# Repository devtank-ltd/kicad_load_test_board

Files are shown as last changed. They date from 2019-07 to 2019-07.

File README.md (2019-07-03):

# kicad_load_test_board
A software controlled load test board for resistive load testing of products

Copyright Devtank Ltd 2019.

This documentation describes Open Hardware and is licensed under the CERN OHL v. 1.2.
You may redistribute and modify this documentation under the terms of the CERN OHL v.1.2. (http://ohwr.org/cernohl). This documentation is distributed WITHOUT ANY EXPRESS OR IMPLIED WARRANTY, INCLUDING OF MERCHANTABILITY, SATISFACTORY QUALITY AND FITNESS FOR A PARTICULAR PURPOSE. Please see the CERN OHL v.1.2 for applicable conditions

This folder contains the load test board hardware schematics and pcb layout files 

You will need Kicad to open hardware design files.

Test and measurement products can be purchased directly from Devtank Ltd.

Please contact:
Tim Telford
Technical Director - Devtank Ltd
+44 (0)1335 818014

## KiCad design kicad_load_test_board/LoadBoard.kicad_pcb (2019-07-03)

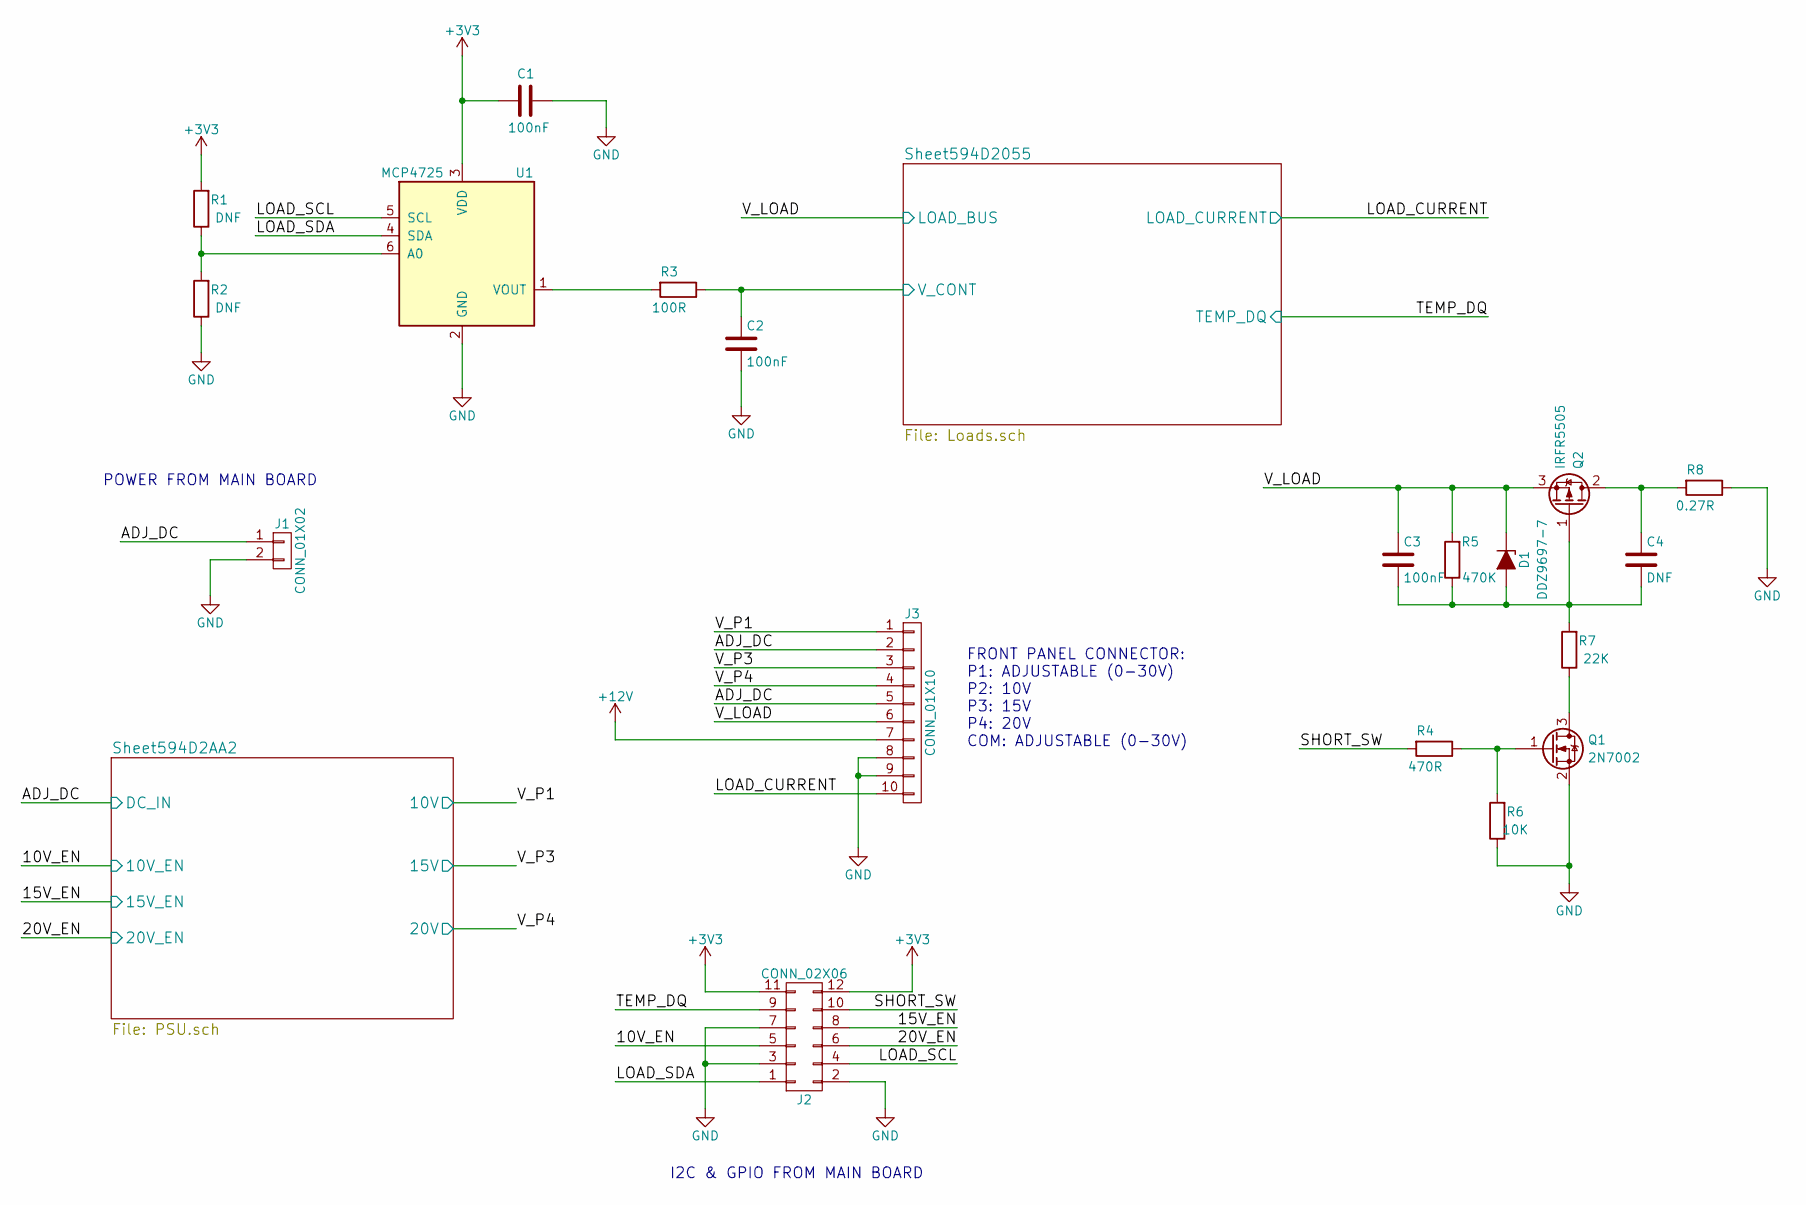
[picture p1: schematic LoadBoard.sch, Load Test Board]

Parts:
C1, C2, C3: 100nF; C_0603
C4: DNF; C_0603
D1: DDZ9697-7; D_SOD-123
J1: CONN_01X02; Molex_MiniFit-JR-5556-02A_2x01x4.20mm_Straight
J2: CONN_02X06; IDC_Header_Straight_12pins
J3: CONN_01X10; Molex_KK-6410-10_10x2.54mm_Straight
Q1: 2N7002; SOT-23
Q2: IRFR5505; TO-252-3_TabPin2
R1, R2: DNF; R_0603
R3: 100R; R_0603
R4: 470R; R_0603
R5: 470K; R_0603
R6: 10K; R_0603
R7: 22K; R_0603
R8: 0.27R; R_2816
U1: MCP4725; SOT-23-6

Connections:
+3V3: C1.2, J2.11, J2.12, R1.2, U1.3 (VDD); also elsewhere on the board
+12V: J3.7; also elsewhere on the board
/10V_EN: J2.5; also elsewhere on the board
/15V_EN: J2.8; also elsewhere on the board
/20V_EN: J2.6; also elsewhere on the board
/ADJ_DC: J1.1, J3.2, J3.5; also elsewhere on the board
/LOAD_CURRENT: J3.10; also elsewhere on the board
/LOAD_SCL: J2.4, U1.5 (SCL)
/LOAD_SDA: J2.1, U1.4 (SDA)
/SHORT_SW: J2.10, R4.2
/Sheet594D2055/V_CONT: C2.1, R3.1; also elsewhere on the board
/TEMP_DQ: J2.9; also elsewhere on the board
/V_LOAD: C3.1, D1.1 (K), J3.6, Q2.3 (S), R5.2; also elsewhere on the board
/V_P1: J3.1; also elsewhere on the board
/V_P3: J3.3; also elsewhere on the board
/V_P4: J3.4; also elsewhere on the board
GND: C1.1, C2.2, J1.2, J2.2, J2.3, J2.7, J3.8, J3.9, Q1.2 (S), R2.1, R6.1, R8.1, U1.2 (GND); also elsewhere on the board
unnamed: C3.2, C4.2, D1.2 (A), Q2.1 (G), R5.1, R7.2
unnamed: C4.1, Q2.2 (D), R8.2
unnamed: Q1.1 (G), R4.1, R6.2
unnamed: Q1.3 (D), R7.1
unnamed: R1.1, R2.2, U1.6 (A0)
unnamed: R3.2, U1.1 (VOUT)

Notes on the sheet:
POWER FROM MAIN BOARD
I2C & GPIO FROM MAIN BOARD
FRONT PANEL CONNECTOR: P1: ADJUSTABLE (0-30V) P2: 10V P3: 15V P4: 20V COM: ADJUSTABLE (0-30V)

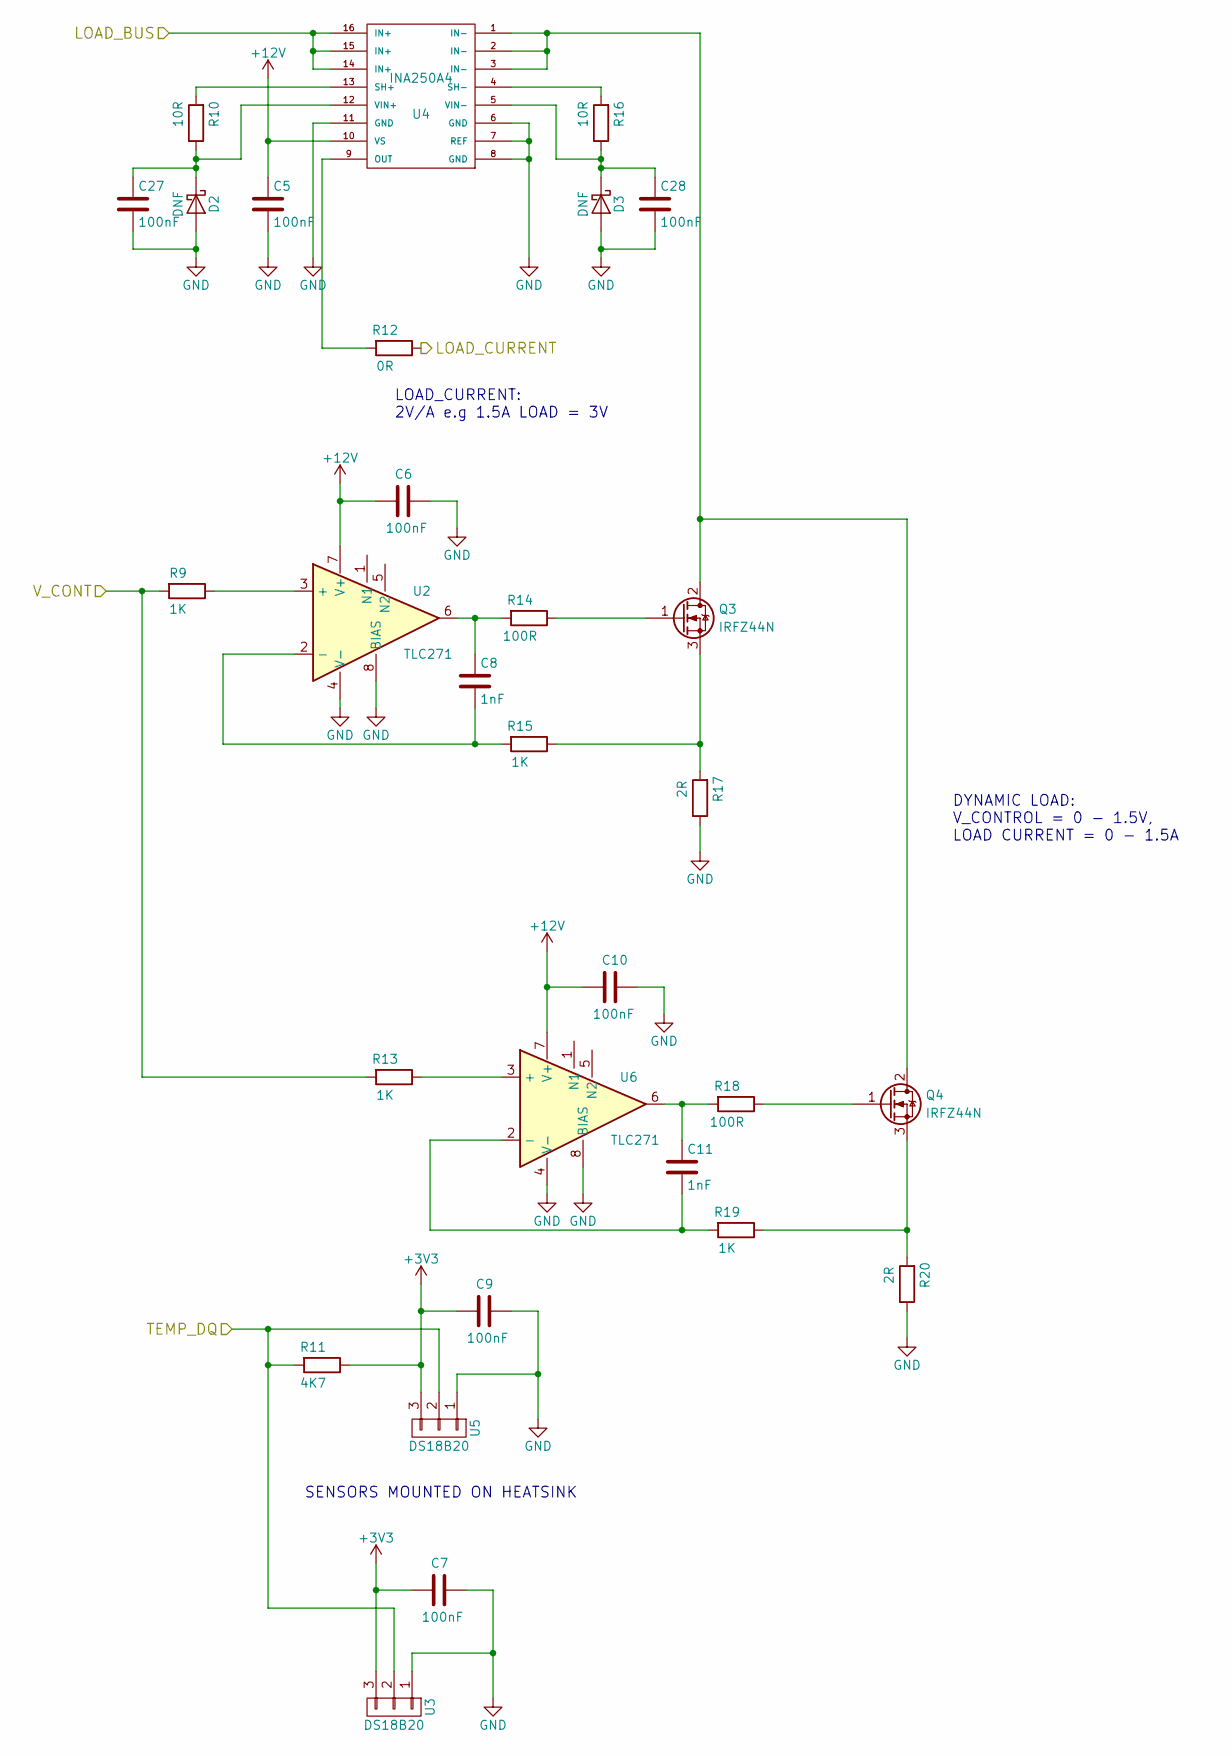
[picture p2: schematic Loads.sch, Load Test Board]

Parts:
C5, C6, C7, C9, C10, C27, C28: 100nF; C_0603
C8, C11: 1nF; C_0603
D2, D3: DNF; D_SOD-123
Q3, Q4: IRFZ44N; TO-220_Vertical
R9, R13, R15, R19: 1K; R_0603
R10, R16: 10R; R_0603
R11: 4K7; R_0603
R12: 0R; R_0603
R14, R18: 100R; R_0603
R17, R20: 2R; R_4527
U2, U6: TLC271; SOIC-8_3.9x4.9mm_Pitch1.27mm
U3, U5: DS18B20; TO-92_Inline_Narrow_Oval
U4: INA250A4; TSSOP-16_4.4x5mm_Pitch0.65mm

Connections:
+3V3: C7.2, C9.2, R11.1, U3.3, U5.3; also elsewhere on the board
+12V: C5.1, C6.2, C10.2, U2.7 (V+), U4.10 (VS), U6.7 (V+); also elsewhere on the board
/LOAD_CURRENT: R12.1; also elsewhere on the board
/Sheet594D2055/V_CONT: R9.2, R13.2; also elsewhere on the board
/TEMP_DQ: R11.2, U3.2, U5.2; also elsewhere on the board
/V_LOAD: U4.14 (IN+), U4.15 (IN+), U4.16 (IN+); also elsewhere on the board
GND: C5.2, C6.1, C7.1, C9.1, C10.1, C27.2, C28.2, D2.2 (A), D3.2 (A), R17.1, R20.1, U2.4 (V-), U2.8 (BIAS), U3.1, U4.6 (GND), U4.7 (REF), U4.8 (GND), U4.11 (GND), U5.1, U6.4 (V-), U6.8 (BIAS); also elsewhere on the board
unnamed: C8.1, R14.2, U2.6
unnamed: C8.2, R15.2, U2.2 (-)
unnamed: C11.1, R18.2, U6.6
unnamed: C11.2, R19.2, U6.2 (-)
unnamed: C27.1, D2.1 (K), R10.1, U4.12 (VIN+)
unnamed: C28.1, D3.1 (K), R16.1, U4.5 (VIN-)
unnamed: Q3.1 (G), R14.1
unnamed: Q3.2 (D), Q4.2 (D), U4.1 (IN-), U4.2 (IN-), U4.3 (IN-)
unnamed: Q3.3 (S), R15.1, R17.2
unnamed: Q4.1 (G), R18.1
unnamed: Q4.3 (S), R19.1, R20.2
unnamed: R9.1, U2.3 (+)
unnamed: R10.2, U4.13 (SH+)
unnamed: R12.2, U4.9 (OUT)
unnamed: R13.1, U6.3 (+)
unnamed: R16.2, U4.4 (SH-)

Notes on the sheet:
DYNAMIC LOAD: V_CONTROL = 0 - 1.5V, LOAD CURRENT = 0 - 1.5A
LOAD_CURRENT: 2V/A e.g 1.5A LOAD = 3V
SENSORS MOUNTED ON HEATSINK

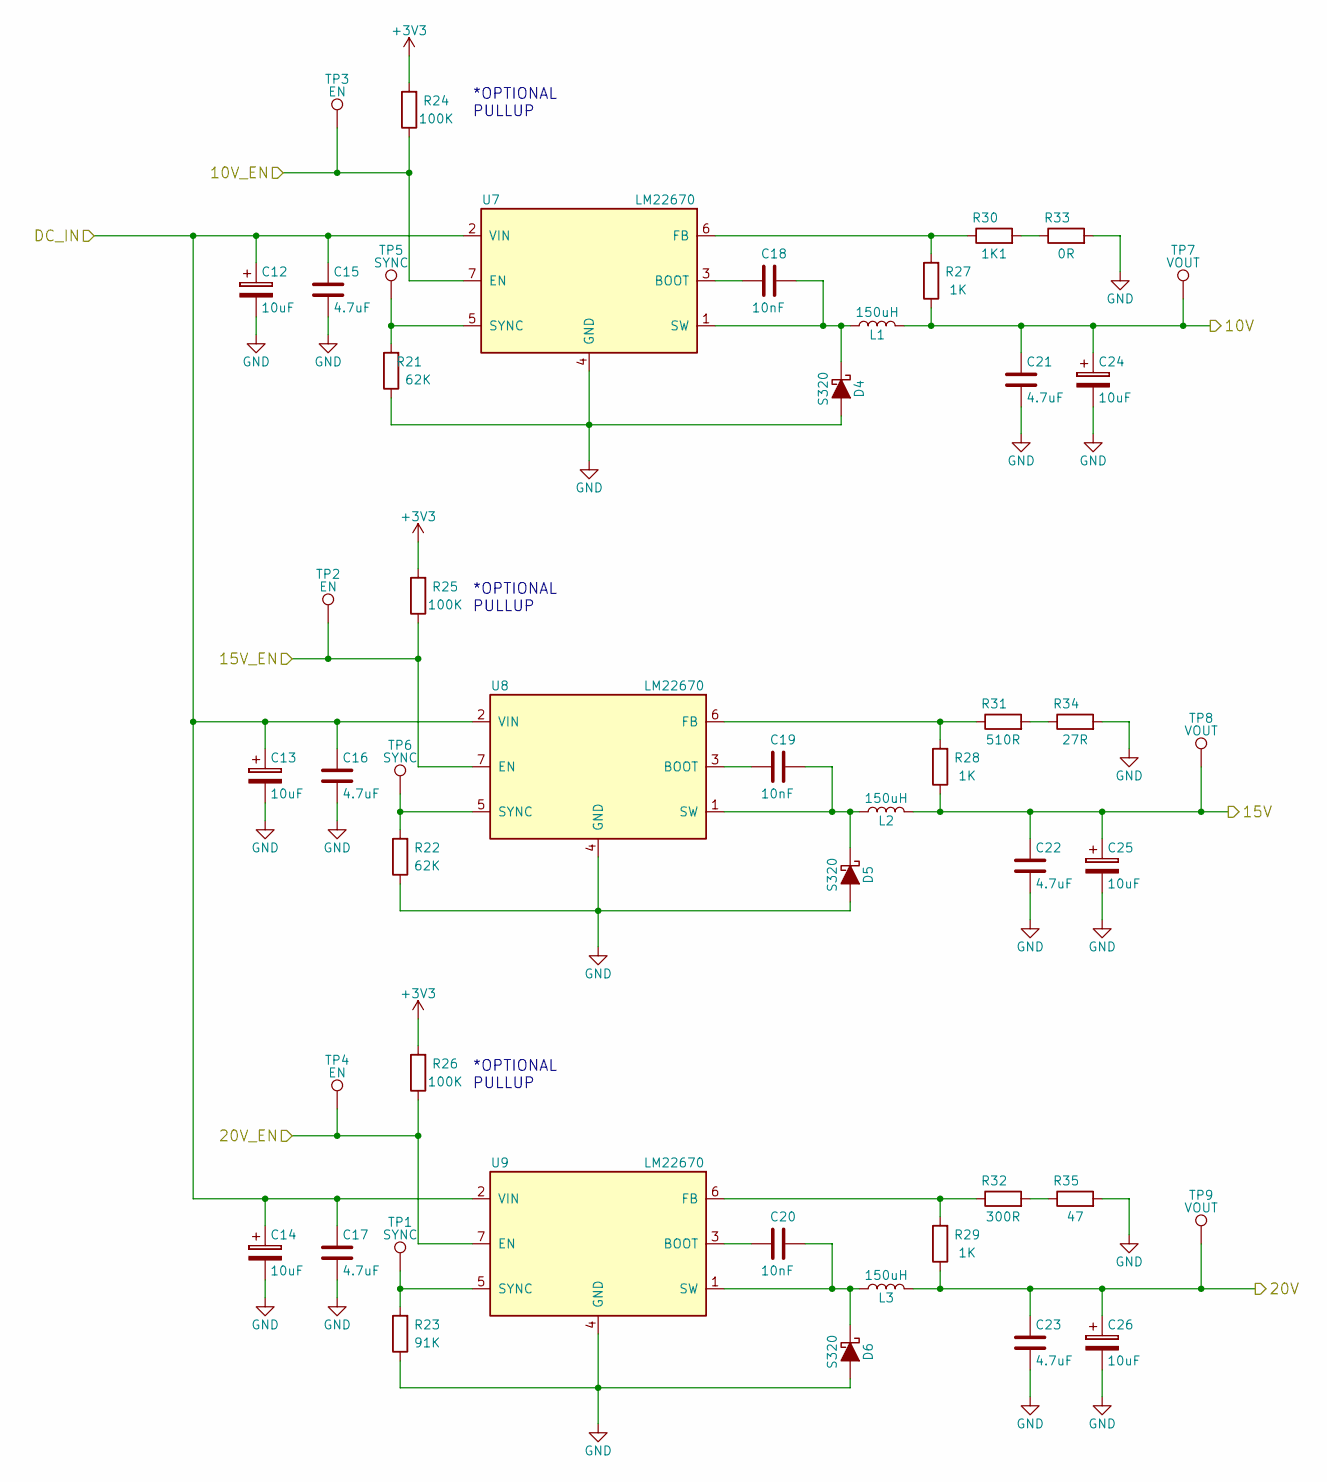
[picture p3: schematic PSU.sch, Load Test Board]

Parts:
C12, C13, C14, C24, C25, C26: 10uF; CP_Elec_6.3x7.7
C15, C16, C17, C21, C22, C23: 4.7uF; C_1210
C18, C19, C20: 10nF; C_0603
D4, D5, D6: S320; D_SMB
L1, L2, L3: 150uH; Inductor_13x13
R21, R22: 62K; R_0603
R23: 91K; R_0603
R24, R25, R26: 100K; R_0603
R27, R28, R29: 1K; R_0603
R30: 1K1; R_0603
R31: 510R; R_0603
R32: 300R; R_0603
R33: 0R; R_0603
R34: 27R; R_0603
R35: 47; R_0603
TP1, TP5, TP6: SYNC; Measurement_Point_Round-TH_Small
TP2, TP3, TP4: EN; Measurement_Point_Round-TH_Small
TP7, TP8, TP9: VOUT; Measurement_Point_Round-TH_Small
U7, U8, U9: LM22670; TO-263-7_TabPin4

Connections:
+3V3: R24.2, R25.2, R26.2; also elsewhere on the board
/10V_EN: R24.1, TP3.1, U7.7 (EN); also elsewhere on the board
/15V_EN: R25.1, TP2.1, U8.7 (EN); also elsewhere on the board
/20V_EN: R26.1, TP4.1, U9.7 (EN); also elsewhere on the board
/ADJ_DC: C12.1, C13.1, C14.1, C15.1, C16.1, C17.1, U7.2 (VIN), U8.2 (VIN), U9.2 (VIN); also elsewhere on the board
/V_P1: C21.1, C24.1, L1.2, R27.1, TP7.1; also elsewhere on the board
/V_P3: C22.1, C25.1, L2.2, R28.1, TP8.1; also elsewhere on the board
/V_P4: C23.1, C26.1, L3.2, R29.1, TP9.1; also elsewhere on the board
GND: C12.2, C13.2, C14.2, C15.2, C16.2, C17.2, C21.2, C22.2, C23.2, C24.2, C25.2, C26.2, D4.2 (A), D5.2 (A), D6.2 (A), R21.1, R22.1, R23.1, R33.2, R34.2, R35.2, U7.4 (GND), U8.4 (GND), U9.4 (GND); also elsewhere on the board
unnamed: C18.1, D4.1 (K), L1.1, U7.1 (SW)
unnamed: C18.2, U7.3 (BOOT)
unnamed: C19.1, D5.1 (K), L2.1, U8.1 (SW)
unnamed: C19.2, U8.3 (BOOT)
unnamed: C20.1, D6.1 (K), L3.1, U9.1 (SW)
unnamed: C20.2, U9.3 (BOOT)
unnamed: R21.2, TP5.1, U7.5 (SYNC)
unnamed: R22.2, TP6.1, U8.5 (SYNC)
unnamed: R23.2, TP1.1, U9.5 (SYNC)
unnamed: R27.2, R30.1, U7.6 (FB)
unnamed: R28.2, R31.1, U8.6 (FB)
unnamed: R29.2, R32.1, U9.6 (FB)
unnamed: R30.2, R33.1
unnamed: R31.2, R34.1
unnamed: R32.2, R35.1

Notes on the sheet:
*OPTIONAL PULLUP

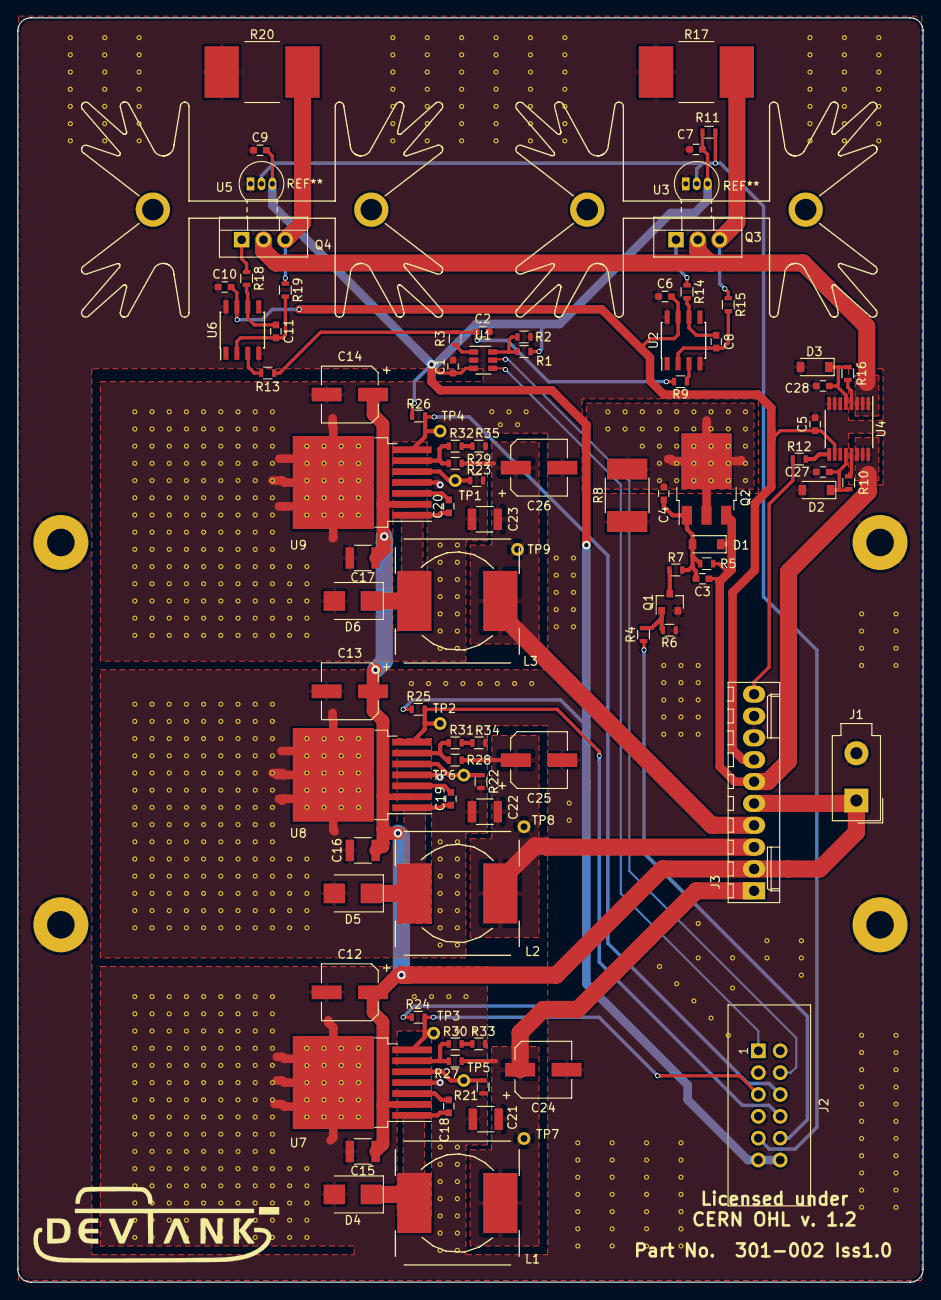
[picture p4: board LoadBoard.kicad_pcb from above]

Board: 2 copper layers, 105.2 x 147.0 mm, 97 parts (0 on the bottom side), 54 nets.

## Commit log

2019-07-03 Add KiCAD project files
    [DevtankProject.kicad_pcb, DevtankProject.sch]
2019-07-03 copied legacy project to new git repo
    [DevtankProject.kicad_pcb, DevtankProject.sch, LoadBoard.kicad_pcb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]
2019-07-03 house keeping documents
    [LoadBoard.kicad_pcb]
